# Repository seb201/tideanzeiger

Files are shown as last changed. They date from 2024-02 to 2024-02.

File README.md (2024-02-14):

# Tideanzeiger

Groß (DSC01956)
<br>

Dieses Projekt visualisiert den Wasserstand von Flüssen oder der Küste mit Hilfe eines ESP32, einer LED-Matrix-Anzeige und einzeln ansteuerbaren LEDs.<br>
Es zeigt den Wasserstand in Zentimetern auf einem LED-Matrix-Display an.<br>
Bei Sturmflut leuchten alle LEDs rot.<br>
Wenn die oberste LED grün leuchtet, steigt das Wasser (Flut).<br>
Leuchtet die unterste LED grün, läuft das Wasser ab (Ebbe).<br>
50 blaue LEDs signalisieren weithin sichtbar den Wasserstand.<br>

Das Projekt entstand im Rahmen einer Abschlussprüfung zum IT-Systemelektroniker im Jahr 2017.<br>

## Herkunft der Daten
Die benötigten Daten zur Anzeige lassen sich auf der Internetseite pegelonline.de auslesen.
Diese Seite wird vom Wasser- und Schifffahrtsamt betrieben und bietet einen Datenabruf im JSON-Format an.
Über folgenden Link können alle verfügbaren Stationen angezeigt werden: https://pegelonline.wsv.de/webservices/rest-api/v2/stations.<br>
Wenn Sie beispielsweise die Stationen für Wilhelmshaven anzeigen möchten, suchen Sie einfach mit Strg+F nach Wilhelmshaven. Wenn keine Daten angezeigt werden, klicken Sie oben im Browser auf 'Rohdaten' (z.B. bei Firefox, siehe Bild).
Dank der umfangreichen Dokumentation der API-Schnittstelle lässt sich schnell die passende URL zusammenstellen.
<br>
Bildschirmfoto 2024-02-13 um 17 42 12
<br>
Die Stationen können unter https://www.pegelonline.wsv.de/gast/karte/standard übersichtlicher dargestellt werden, leider ist hier die erforderliche UUID nicht ersichtlich.
<br>

Die Stations-ID (Identifikationsnummer) des Alten Vorhafens lautet: 48d6b739-a79d-4f8b-b47a-50eaaa7ef1b1.
Die fertige URL lautet: https://pegelonline.wsv.de/webservices/rest-api/v2/stations/48d6b739-a79d-4f8b-b47a-50eaaa7ef1b1/W/currentmeasurement.json.<br>

Beim Öffnen dieser URL im Browser erscheint folgende Ausgabe:<br>
``{
  "timestamp": "2017-03-31T08:06:00+02:00",
  "value": 384.0,
  "trend": -1,
  "stateMnwMhw": "unknown",
  "stateNswHsw": "unknown"
}``<br>

- **Timestamp** Das Datum und die Uhrzeit werden lediglich für die Weboberfläche benötigt, um anzuzeigen, wann die Daten zuletzt aktualisiert wurden.<br>
- **Value** Der Wasserstand wird in Zentimetern über Pegelnull angegeben. Pegelnull liegt normalerweise 500 cm unter NN (Normal null). Diese Festlegung sorgt dafür, dass alle Wasserstände im Tidebereich (siehe Glossar) ein positives Vorzeichen haben.<br>
- **Trend** Der Wert signalisiert, ob sich Wasser steigt (Wert = 1), abfließt (Wert = -1) oder sich der Wasserstand nicht verändert (Wert = 0).<br>
- **stateMnwMhw** brauchen wir nicht<br>
- **stateNswHsw** brauchen wir nicht<br>

## Installation

Benötigt wird ein:
- 1X ESP32 (früher lief das Projekt mit einem Arduino Leonardo Ethernet, der ist aber zu schwach, da mittlerweile die Daten nur noch verschlüsselt vom WSA Server abgerufen werden können)
- einzel Ansteuerbare RGB-LEDs vom Typ WS2812 (Anzahl je nachdem wie lang die Anzeige werden soll. Ich verwende 54 LEDs). Ich verwende LEDs mit 30 Stück pro Meter, natürlich können auch welche mit mehr als 30 genommen werden, dann muss aber evtl. ein stärkeres Netzteil verbaut werden
- 2X Matrix LEDs mit dem Controller MAX7219
- einen Kasten wo der ESP32 und die Marrix LEDs einkommen. Ich habe diesen hier verwendet: <br>https://www.reichelt.de/desktop-box-129-x-64-x-41-9-mm-rnd-455-00102-p193316.html<br> allerdings scheint es den zumindest bei Reichelt nicht mehr zu geben
- eine Holzlatte (1 cm dick und 4 cm breit, länge je nach Deckenhöhe, ich habe 2 Meter genommen)
- 2X bzw. 2 Meter, Alu Schienen für die LEDs. Ich habe diese hier genommen:<br> LED ALU PROFIL N ELOXIERT, 100CM INKL. ABDECKUNG OPAL ZUM EINSCHIEBEN U. 3 MONTAGECLIPS https://www.led-konzept.de/LED-Alu-Profil-N-eloxiert-100cm-inkl-Abdeckung-opal-zum-Einschieben-u-3-Montageclips
- 5 V Netzteil, je nach Helligkeit und Anzahl der LEDs mit entsprechender Leistung (eventuell ein einfaches USB Netzteil)

Sollte sowieso jeder Bastler zu Hause haben:
- Dremel 
- Schrauben
- Säge (zum sägen der Holzlatte und der Alu Schienen)
- Lötkolben
- Litze

Für die ordentlichen :smile::
- eine Lochrasterplatine (hab ich mir gespart, so viel ist nicht zu verkabeln)<br><br>

## Programmierung

Es mussen folgende externe Arduino Bibliotheken installiert werden:

- ArduinoJson
- MaxMatrix
- FastLED
- AsyncTCP (für OTA Updates und Weboberfläche)
- ESPAsyncWebServer (für OTA Updates und Weboberfläche)
- AsyncElegantOTA (für OTA Updates und Weboberfläche)<br><br>

Diese Dinge müssen individuell im Quellcode angepasst werden:<br>
- ``const char* ssid = "SSID";``<br>
- ``const char* password = "Passwort";``<br>
- ``#define NUM_LEDS 54`` je nachdem wie viele LEDs man nutzen möchte<br>
- ``IPAddress local_IP(192, 168, 0, 15);`` IP Adresse eintragen<br>
- ``IPAddress gateway(192, 168, 0, 2);`` Gateway eintragen<br>
- ``IPAddress subnet(255, 255, 255, 0);`` Subnetz eintragen<br>
- ``IPAddress primaryDNS(192, 168, 0, 2);`` DNS eintragen<br>
- ``if (value > 800) {`` bei über 800 cm Wasserpegel gehen alle LEDs auf rot, dieser Wert kann natürlich angepasst werden<br>
- ``delay(300000);`` hier kann man eintragen, wie oft die Daten aktualisiert werden sollen (in Millisekunden. 300000, also 300 Sekunden, also alle 5 Minuten eine Aktualisierung<br>
- ``http.begin("https://www.pegelonline.wsv.de/webservices/rest-api/v2/stations/f85bd17b-06c7-49bd-8bfc-ee2bf3ffea99/W/currentmeasurement.json");``<br>
  Statt ``f85bd17b-06c7-49bd-8bfc-ee2bf3ffea99`` muss man seine Station ID eintragen<br>

## Verkabelung

Matrix Anzeige:
- data muss an Pin 18 des ESPs
-  load muss an Pin 19 des ESPs
- clk muss an Pin 21 des ESPs
- Stromversorgung der Matrix Anzeige über 5V also VIN am ESP<br>

LEDs:
- DATA_PIN muss an Pin 4 des ESPs
- Stromversorgung des LEDs über 5V also VIN am ESP<br>

Die Matrix LEDs bestehen aus zwei Modulen, die miteinander verlötet werden müssen.<br>
Mittel (DSC01915)<br>
Die Halterung für die Matrix LEDs kann mit einem 3D Drucker ausgedruckt werden (3D Datei als STL und SketchUp liegen bei).<br><br>

## Weboberfläche

Gibt man die IP Adresse des Tidenanzeigers in einen Webbrowser ein, wird eine Weboberfläche angezeigt:<br>
Bildschirmfoto 2024-02-13 um 18 25 06<br>
Auf dieser Seite werden die Daten vom Pegel und die WLAN-Empfangsstärke angezeigt.<br>
Außerdem können Firmware-Updates eingespielt werden. Der Standard-Benutzername lautet 'Admin' und das Passwort '1234'. Diese Zugangsdaten können im Quellcode angepasst werden.<br><br>

## Was noch verbessert werden kann

- die Weboberfläche zeigt manchmal komische Werte für den Timestamp an, wahrscheinlich ein Dateityp Problem, stört aber nicht weiter

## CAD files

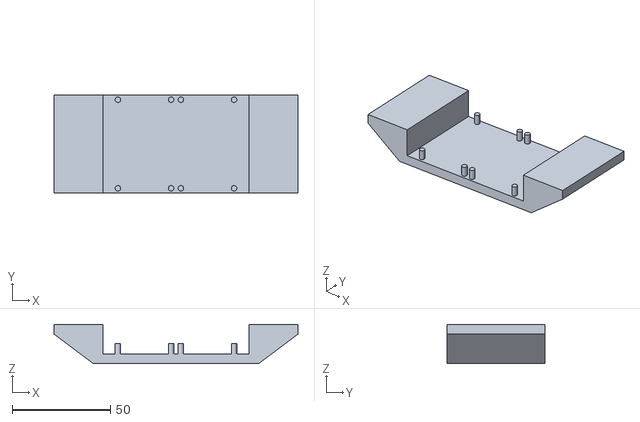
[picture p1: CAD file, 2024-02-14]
3D Modell/Matrix Halter2.stl
124.0 x 50.0 x 20.0

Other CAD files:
3D Modell/Matrix Halter2.skp

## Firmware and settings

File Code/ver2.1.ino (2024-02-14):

/*

  https://github.com/seb201/tideanzeiger


  Changelog:
  ver0.6 = Andere Einteilung der LEDs pro cm Wasser, Update von /library/FastLed/platforms/esp/32/clockless_32.h
  ver0.7 = Einbindung des Temperatursensors
  ver0.8 = Entfernung Temperatursensor, Z 294 delay von 1000 ms statt 500 ms, Z227 disconnect() könnte man auskommentiert
  ver0.9
  ver1.0 = Auf https:// umgestellt
  ver2.0 = alles neuprogrammiert
  ver2.1 = Ebbe und Flut wird wieder angezeigt

  Zukunft:
  Link zum Update auf local_IP umgestellt (für DHCP wichtig), HTML angepasst, Timestamp keine komischen Werte mehr (wahrscheinlich falsches Datenformat)

  Benötigte Bibliotheken mit der getesteten Version (evtl. funktionieren auch neuere Versionen)

    WiFi in Version 2.0.0
    WiFiClientSecure in Version 2.0.0
    ArduinoJson in Version 6.14.0
    HTTPClient in Version 2.0.0
    MAXMATRIX
    SPI in Version 2.0.0
    FastLED in Version 3.5.0
    AsyncTCP in Version 1.1.1
    ESP Async WebServer in Version 1.2.3
    AsyncElegantOTA in Version 2.2.7



  Verkabelung:

  Matrix Anzeige:
    data muss an Pin 18 des ESPs
    load muss an Pin 19 des ESPs
    clk muss an Pin 21 des ESPs

  LEDs:
    DATA_PIN muss an Pin 4 des ESPs

*/
float ver = 2.1;

#include <WiFi.h>
#include <WiFiClientSecure.h>
#include <ArduinoJson.h>  //JSON
#include <HTTPClient.h>   //API-Abfrage
#include <MaxMatrix.h>
#define FASTLED_ALLOW_INTERRUPTS 0
#include <Arduino.h>
#include <SPI.h>
#include "FastLED.h"
#include <AsyncTCP.h>
#include <ESPAsyncWebServer.h>
#include <AsyncElegantOTA.h>

// WIFI-Zugangsdaten
const char* ssid = "SSID";
const char* password = "Passwort";

AsyncWebServer server(80);

#include "Numbers.h"
#include "html.h"
#include <pgmspace.h>

//Diese Zeilen Definieren, wann bei dem Matrix LED Modul welche LEDs angehen bei einem bestimmten Buchstaben oder bei einer bestimmten Zahl
int data = 18;                           // DIN pin von dem MAX7219 Modul
int load = 19;                           // CS pin von dem MAX7219 Modul
int clk = 21;                            // CLK pin von dem MAX7219 Modul
int maxInUse = 2;                        // definiert, wie viele Matrix LED Module angeschlossen sind
MaxMatrix m(data, load, clk, maxInUse);  // zusammenfassung der einzelnen Defintionen
byte buffer[100];

// LED Einstellungen
#define NUM_LEDS 54    // definiert wie viele LEDs der LED Stripe hat
#define DATA_PIN 4     // definiert den Daten Pin des LED Stripes
CRGB leds[NUM_LEDS];   // Array von LEDs
#define BRIGHTNESS 15  // definiert die Helligkeit der LEDs
int fadeAmount = 5;    // Set the amount to fade I usually do 5, 10, 15, 20, 25 etc even up to 255.
int brightness = 0;

// IP Einstellungen
byte mac[] = { 0xDE, 0xAD, 0xBE, 0xEF, 0xFE, 0xED };  // definition der MAC Adresse
IPAddress local_IP(192, 168, 0, 15);
IPAddress gateway(192, 168, 0, 2);
IPAddress subnet(255, 255, 255, 0);
IPAddress primaryDNS(192, 168, 0, 2);
IPAddress secondaryDNS(8, 8, 4, 4);    // Zweiter DNS Server optional
String hostname = "Tidenanzeiger";

//Meldungen auf dem Matrixdisplay
char string1[] = " Tidenanzeiger        ";
char string2[] = "Keine Verbindung zum WSA Server         ";
char string3[] = "Keine Verbindung zum WLAN         ";

int value = 0;
int trend = 0;
const char* timestamp = 0;


// Variable zur Erkenneung, ob Ebbe oder Flut
int value_alt = 0;

int versuch = 1;
int neustart = 0;

// Umwandlung der Werte zur Anzeige auf Weboberfläche
String processor(const String& var) {
  //Serial.println(var);
  if (var == "VALUE") {
    return String(value);
  } else if (var == "TREND") {
    return String(trend);
  } else if (var == "TIMESTAMP") {
    return String(timestamp);
    //return String(string_timestamp);
  } else if (var == "VER") {
    return String(ver, 1);
  } else if (var == "IP") {
    return String(WiFi.localIP());
  } else if (var == "RSSI") {
    return String(WiFi.RSSI());
  }
  return String();
}


void setup() {

  Serial.begin(115200);

  Serial.print("Tidenanzeiger gestartet  VERSION: ");
  Serial.println(ver, 1);

  m.init();           // initialisierung des Matrix Modus
  m.setIntensity(6);  // Helligkeit des Matrix Moduls (von 0 bis 15)

  // Gibt auf der Matrixanzeige string1 aus
  printStringWithShift(string1, 100);

  // Initialisierung der LEDs
  FastLED.addLeds<WS2812B, DATA_PIN, GRB>(leds, NUM_LEDS);
  FastLED.setBrightness(BRIGHTNESS);  //LED Helligkeit
  delay(500);
  //FastLED.clear();
  fill_solid(leds, NUM_LEDS, CRGB::Black);

  WLANverbinden();

  // Initialisierung des Webservers
  server.on("/", HTTP_GET, [](AsyncWebServerRequest * request) {
    request->send_P(200, "text/html", index_html, processor);
  });

  // Initialisierung der OTA Servers
  AsyncElegantOTA.begin(&server, "admin", "1234");  // Start ElegantOTA
  server.begin();
  Serial.println("AsyncElegantOTA started");
  Serial.println("");

  delay(500);
}



void loop() {

  // Wird benötigt, damit nach einem Update der ESP automatisch neustartet - Wird wohl in der neusten Version nicht mehr benötigt
  //AsyncElegantOTA.loop();

  runterladen();

  String value_string = String(value);
  matrix(value_string);
  ebbeflut();

  // Prüft auf Sturmflut
  if (value > 800) {  //wenn höher als 800 dann Sturmflutmodus
    sturm();
  } else {
    anzeigeRGB();
  }

  neustart = neustart + 1;

  // Täglicher Neustart
  if (neustart == 720) {
    Serial.println("Täglicher Neustart");
    delay(1000);
    ESP.restart();
  }


  delay(300000);  //loop wird alle 5 Minuten gestartet, D.h. alle 5 Minuten wird die Anzeige aktualisiert
}


/**********************************************************************************************************/
void WLANverbinden() {

  if (!WiFi.config(local_IP, gateway, subnet, primaryDNS, secondaryDNS)) {
    Serial.println("STA Failed to configure");
  }

  WiFi.setHostname(hostname.c_str());  //definiert den Hostnamen

  WiFi.begin(ssid, password);  //Internet-Verbindung starten

  delay(3000);

  while (WiFi.status() != WL_CONNECTED) {
    Serial.println("Keine Verbindung zum WLAN");
    fill_solid(leds, NUM_LEDS, CRGB::Yellow); //wenn keine Verbindung zum Wlan, dann alle LEDs gelb
    FastLED.show();
    delay(500);
    Serial.print("Verbindungsversuch:");
    Serial.print(versuch);
    Serial.println("/4");
    Serial.println("20 Sekunden warten");
    printStringWithShift(string3, 100);
    versuch = versuch + 1;
    delay(20000);
    if (versuch == 5) {
      ESP.restart();
    }
  }

  Serial.println("");
  Serial.print("Verbunden mit: ");
  Serial.println(ssid);
  Serial.print("IP address: ");
  Serial.println(WiFi.localIP());
  Serial.print("ESP Mac Address: ");
  Serial.println(WiFi.macAddress());
  Serial.print("Subnet Mask: ");
  Serial.println(WiFi.subnetMask());
  Serial.print("Gateway IP: ");
  Serial.println(WiFi.gatewayIP());
  Serial.print("DNS: ");
  Serial.println(WiFi.dnsIP());
  Serial.print("RSSI: ");
  Serial.println(WiFi.RSSI());
  Serial.println("");

  delay(500);

  // Wird für verschlüsselte Verbindungen mit dem WSA Server benötigt
  WiFiClientSecure client;
}

/**********************************************************************************************************/
void runterladen() {
  if ((WiFi.status() == WL_CONNECTED)) {

    HTTPClient http;  //Instanz von HTTPClient starten


    //Messstation WHV ALTER VORHAFEN
    http.begin("https://www.pegelonline.wsv.de/webservices/rest-api/v2/stations/f85bd17b-06c7-49bd-8bfc-ee2bf3ffea99/W/currentmeasurement.json");  //Abfrage-URL

    //Alternative Messstation WHV NEUER VORHAFEN
    //http.begin("https://www.pegelonline.wsv.de/webservices/rest-api/v2/stations/f77317d9-654f-4f51-925e-004c592049da/W/currentmeasurement.json"); //Abfrage-URL


    int httpCode = http.GET();  //Antwort des Servers abrufen

    // Verarbeitet die über JSON abgerufenen Daten
    if (httpCode == 200) {
      String payload = http.getString();  //Daten in eine Variable speichern
      const size_t capacity = JSON_ARRAY_SIZE(5) + 5 * JSON_OBJECT_SIZE(2) + JSON_OBJECT_SIZE(3) + 200;
      DynamicJsonDocument doc(capacity);
      deserializeJson(doc, payload);

      value = doc["value"];
      trend = doc["trend"];
      timestamp = doc["timestamp"];
      //string_timestamp = doc["string_timestamp"];

      Serial.println(value);
      Serial.println(trend);
      Serial.println(timestamp);
      Serial.println("");

    } else {
      // Gibt einen Fehler aus, wenn keine Verbindung zum WSA Server besteht
      Serial.println("Keine Verbindung zum WSA Server. ESP startet in 2 Minuten neu");
      fill_solid(leds, NUM_LEDS, CRGB::Yellow); //wenn keine Verbindung zum Wlan, dann alle LEDs gelb
      FastLED.show();
      delay(1000);
      printStringWithShift(string2, 100);
      delay(120000);  //wartet 2 Minuten
      ESP.restart();  //und startet dann neu
    }
  }
}

/**********************************************************************************************************/
void matrix(String aktWert) {
  char Buff[80];
  aktWert.toCharArray(Buff, 80);
  printString(Buff);
}

/**********************************************************************************************************/
void printString(char* s) {
  int col = 0;
  while (*s != 0) {
    if (*s < 32) continue;
    char c = *s - 32;
    memcpy_P(buffer, CH + 7 * c, 7);
    m.writeSprite(col, 0, buffer);
    m.setColumn(col + buffer[0], 0);
    col += buffer[0] + 1;
    s++;
  }
}

/**********************************************************************************************************/
void printCharWithShift(char c, int shift_speed) {
  if (c < 32) return;
  c -= 32;
  memcpy_P(buffer, CH + 7 * c, 7);
  m.writeSprite(32, 0, buffer);
  m.setColumn(32 + buffer[0], 0);
  for (int i = 0; i < buffer[0] + 1; i++) {
    delay(shift_speed);
    m.shiftLeft(false, false);
  }
}

/**********************************************************************************************************/
void printStringWithShift(char* s, int shift_speed) {
  while (*s != 0) {
    printCharWithShift(*s, shift_speed);
    s++;
  }
}

/**********************************************************************************************************/
void ebbeflut() {

  // Prüft mittels des vorherigen value Wert, ob der Wasserstand steigt oder sinkt
  if (value - value_alt >= 1) {
    trend = 1;
  }

  if (value - value_alt <= -1) {
    trend = -1;
  }

  if (value == value_alt) {
    trend = 0;
  }

  // Der Wert des Trends wird in die LED Anzeige umgewandelt. 0 keine LED Wasserstand gleichbleibend zur vorherigen Messung, 1 oberste LED grün Flut, -1 unterste LED grün Ebbe
  if (trend == 1) {
    leds[NUM_LEDS - 1] = CRGB::Green;
    leds[0] = CRGB::Black;
  }

  else if (trend == -1) {
    leds[0] = CRGB::Green;
    leds[NUM_LEDS - 1] = CRGB::Black;
  } else {
    leds[NUM_LEDS - 1] = CRGB::Black;
    leds[0] = CRGB::Black;
  }
  FastLED.show();

  value_alt = value;
}


/**********************************************************************************************************/
void anzeigeRGB() {

  // Lässt die LEDs leuchten, je nach Wasserstand
  int anz = value / 16;
  if (anz > 60)
    anz = 60;

  for (int whiteLed = 1; whiteLed < NUM_LEDS - 1; whiteLed = whiteLed + 1) {
    // Turn our current led on to white, then show the leds
    if (whiteLed < anz + 1) {
      leds[whiteLed] = CRGB::Blue;
    }

    else {
      leds[whiteLed] = CRGB::Black;
      // Wait a little bit
      //delay(100);
    }
    // Turn our current led back to black for the next loop around
    //leds[whiteLed] = CRGB::Black;
  }
  FastLED.show();
}

/**********************************************************************************************************/
void sturm() {
  for (int whiteLed = 1; whiteLed < NUM_LEDS - 1; whiteLed = whiteLed + 1) {
    // Turn our current led on to white, then show the leds

    leds[whiteLed] = CRGB::Red; //bei Sturmflut werden allr LEDs auf Rot geschaltet
  }
  // Show the leds (only one of which is set to white, from above)
  FastLED.show();
  // Wait a little bit
  delay(1000);
}

/**********************************************************************************************************/
